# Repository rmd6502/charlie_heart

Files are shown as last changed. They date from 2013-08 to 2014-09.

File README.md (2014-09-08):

Charlie Heart
=============

https://dl.dropboxusercontent.com/u/10205003/VIDEO0005.mp4
Charlieplexed Heart for Mother's day, etc.  The files are for EAGLE cad, will gladly accept pull requests with Kicad files.

David Reeves made a set of step-by-step instructional photos at https://www.flickr.com/photos/dcreeves2000/sets/72157640155673266/

Annie Hsu made me an instructional video at https://www.dropbox.com/s/pq46bvkq2qu05k4/LED%20Heart-SD%20for%20Apple%20Devices.m4v

Parts Manifest
==============

1.  Heart-shaped circuit board
1.  5 x 3Ω resistors, marking "3R0"
1.  1 x 1kΩ resistor, marking "102"
1.  1 x .1µf capacitor, tan
1.  1 x mosfet transistor
1.  1 x pushbutton switch
1.  1 x preprogrammed ATTiny85 processor
1.  20 x red LEDs
1.  1 x battery clip
1.  1 x CR2032 battery

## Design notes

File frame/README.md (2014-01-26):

Updated the case with an all new Openscad one!

Print 2, and you can run a ribbon through the slots for instant gifting.

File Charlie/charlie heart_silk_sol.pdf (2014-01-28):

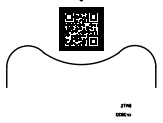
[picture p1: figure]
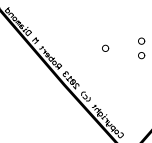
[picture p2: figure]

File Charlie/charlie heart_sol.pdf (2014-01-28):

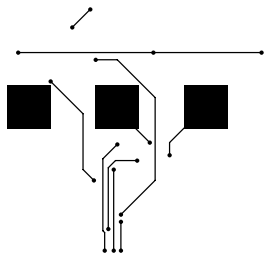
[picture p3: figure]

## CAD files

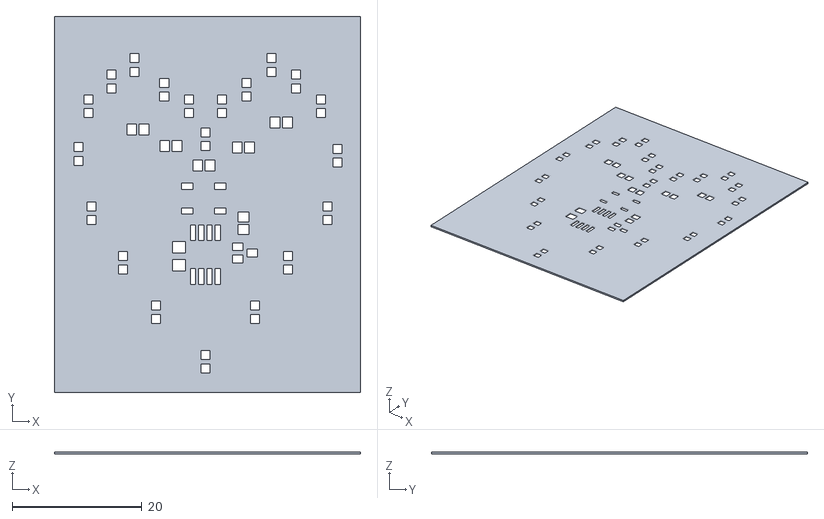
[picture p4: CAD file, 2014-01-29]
Charlie/template.stl
47.1 x 58.0 x 0.3

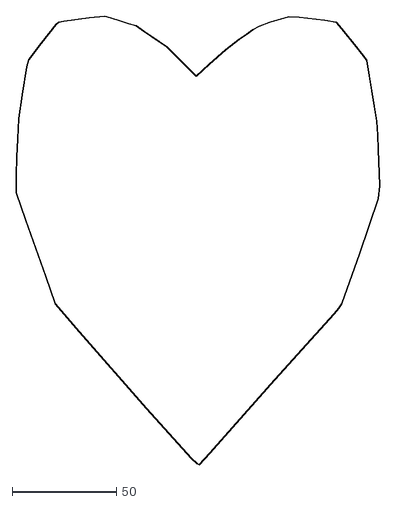
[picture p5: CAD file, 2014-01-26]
frame/inner_heart.dxf
174.2 x 214.6

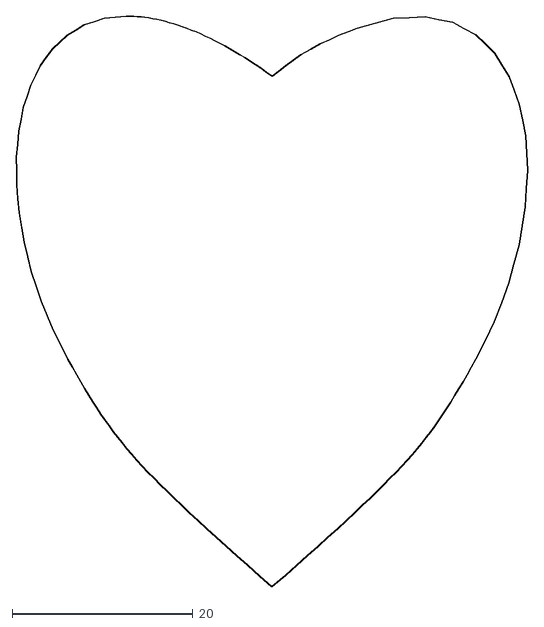
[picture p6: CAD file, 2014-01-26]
frame/outer_heart.dxf
56.6 x 63.2

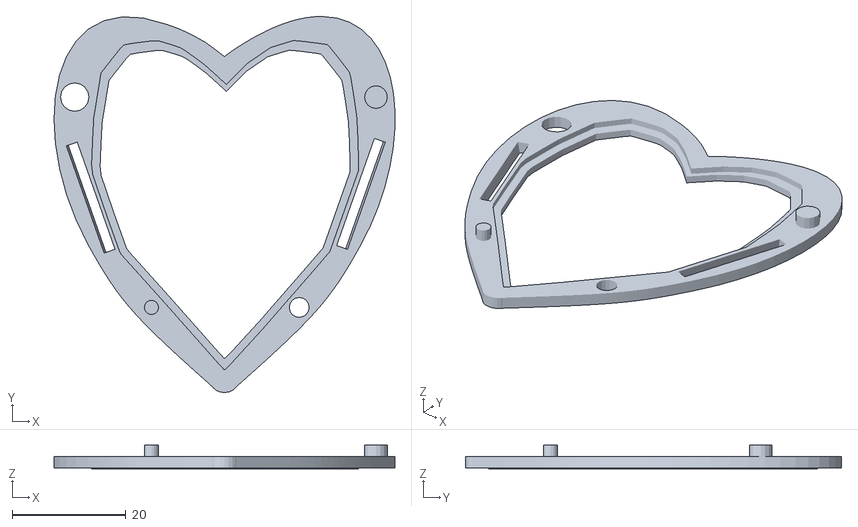
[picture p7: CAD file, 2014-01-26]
frame/heart_board.stl
60.0 x 66.2 x 4.20

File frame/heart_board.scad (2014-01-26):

rotate([0,180,0]) union() {
	difference() {
		translate([-30,0,0]) linear_extrude(2) resize([60,0,0],auto=true) import("outer_heart.dxf");
		translate([-23.5,5,0]) linear_extrude(2) resize([47,0,0],auto=true) import("inner_heart.dxf");
		translate([26.5,53,1]) cylinder(r=2.5,h=2,center=true,$fn=16);
		translate([-13,16,1]) cylinder(r=1.75,h=2,center=true,$fn=16);
		translate([-21.5,26.2,0]) rotate([0,10,19.4]) cube([2,20,3]);
		translate([19.5,26.2,-.5]) rotate([0,-10,-19.4]) cube([2,20,3]);
		// For pointed tip comment this line and the last
		translate([-2.4,0,0]) cube([5,2,2]);
	}
	translate([0,0,1]) difference() {
		translate([-23.5,5,0]) linear_extrude(1.2) resize([47,0,0],auto=true) import("inner_heart.dxf");
		translate([-22,7,0]) linear_extrude(1.2) resize([44,0,0],auto=true) import("inner_heart.dxf");
	}
	translate([-26.5,53,-1]) cylinder(r=2,h=2,center=true,$fn=16);
	translate([13,16,-1]) cylinder(r=1.25,h=2,center=true,$fn=16);
	// for pointed tip comment this line and the indicated one above
translate([0.16,3,0]) scale([1.1,.9,1]) linear_extrude(2) circle(2.2,$fn=20);
}

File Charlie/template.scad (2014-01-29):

render(2) difference() {
	cube([47.15,57.95,.3]);
	minkowski() { 
		translate([3,3,0]) linear_extrude(.2) import ("charlie heart_top_paste.dxf");
		cube(.2);
	}
}

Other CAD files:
Charlie/charlie heart_top_paste.dxf

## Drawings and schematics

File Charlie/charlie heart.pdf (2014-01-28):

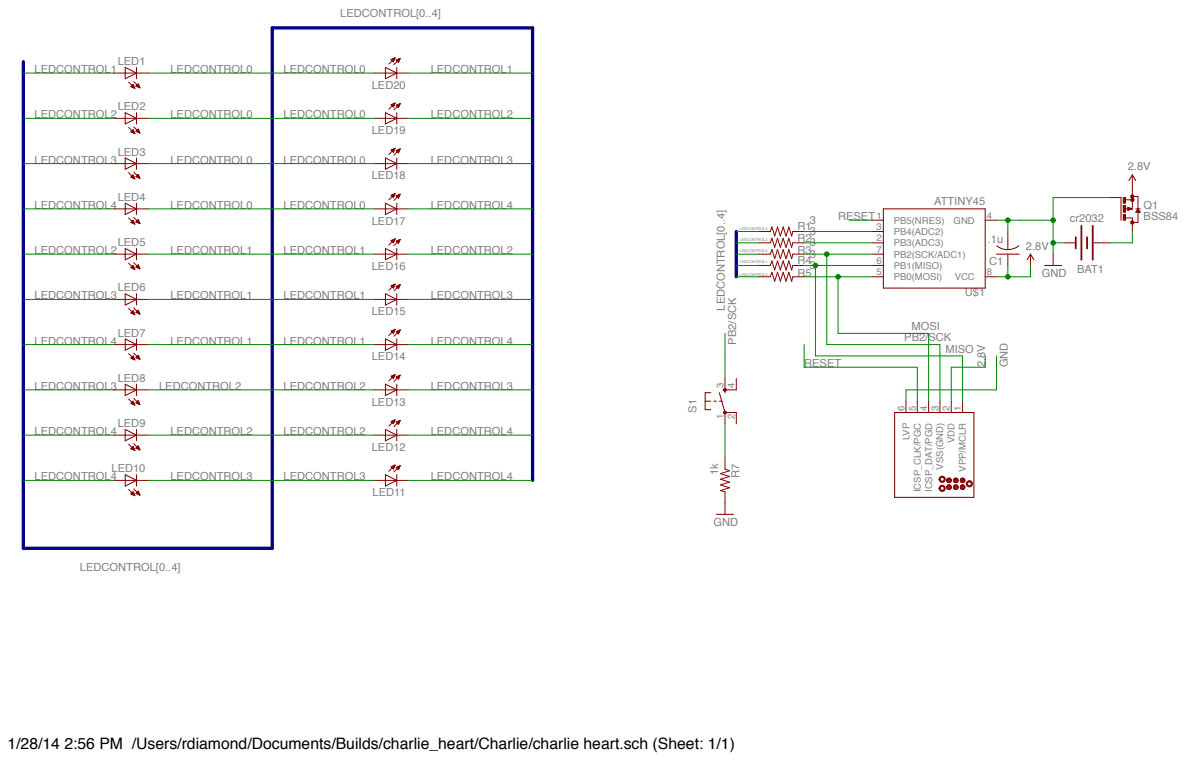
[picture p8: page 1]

LED2 LEDCONTROL2 LEDCONTROL0 | LED20 LEDCONTROL0 LEDCONTROL2

LED3 LEDCONTROL3 LEDCONTROL0 | LED19 LEDCONTROL0 LEDCONTROL3

LED4 LEDCONTROL4 LEDCONTROL0 | LED18 LEDCONTROL0 LEDCONTROL4

LED6 LEDCONTROL3 LEDCONTROL1 | LED16 LEDCONTROL1 LEDCONTROL3

LED7 LEDCONTROL4 LEDCONTROL1 | LED15 LEDCONTROL1 LEDCONTROL4

LED8 LEDCONTROL3 LEDCONTROL2 | LED14 LEDCONTROL2 LEDCONTROL3

LED9 LEDCONTROL4 LEDCONTROL2 | LED13 LEDCONTROL2 LEDCONTROL4

VPP/MCLR 1 VDD 2 VSS(GND) 3 ICSP_DAT/PGD 4 ICSP_CLK/PGC 5 LVP 6

LED10 LEDCONTROL4 LEDCONTROL3 | LED12 LEDCONTROL3 LEDCONTROL4

1/28/14 2:56 PM /Users/rdiamond/Documents/Builds/charlie_heart/Charlie/charlie heart.sch (Sheet: 1/1)

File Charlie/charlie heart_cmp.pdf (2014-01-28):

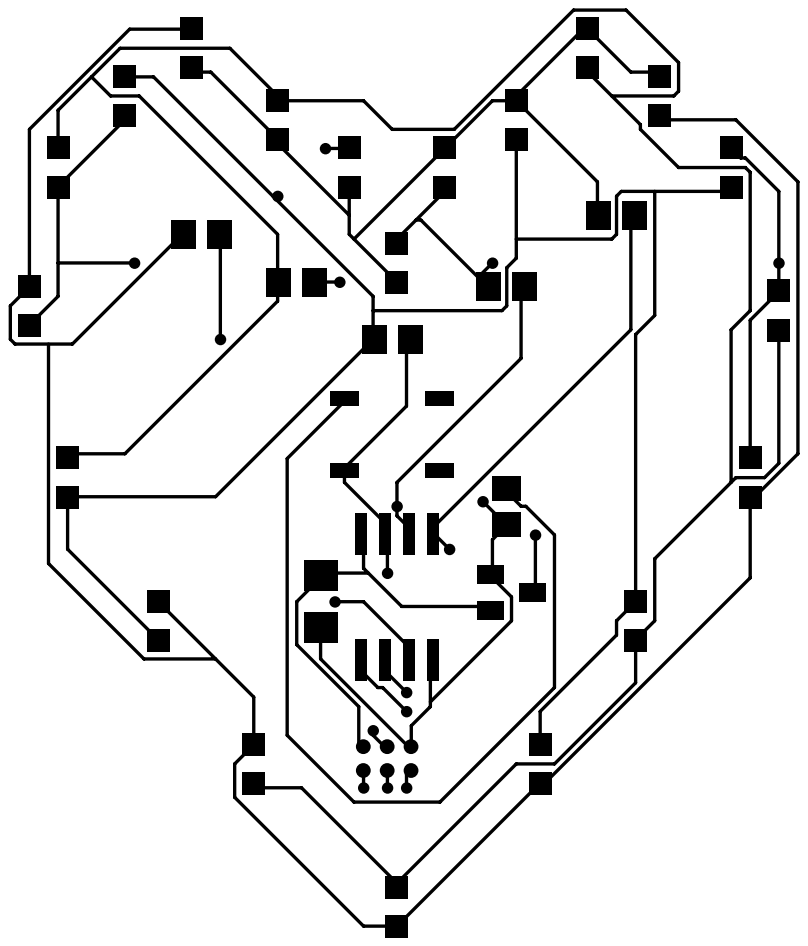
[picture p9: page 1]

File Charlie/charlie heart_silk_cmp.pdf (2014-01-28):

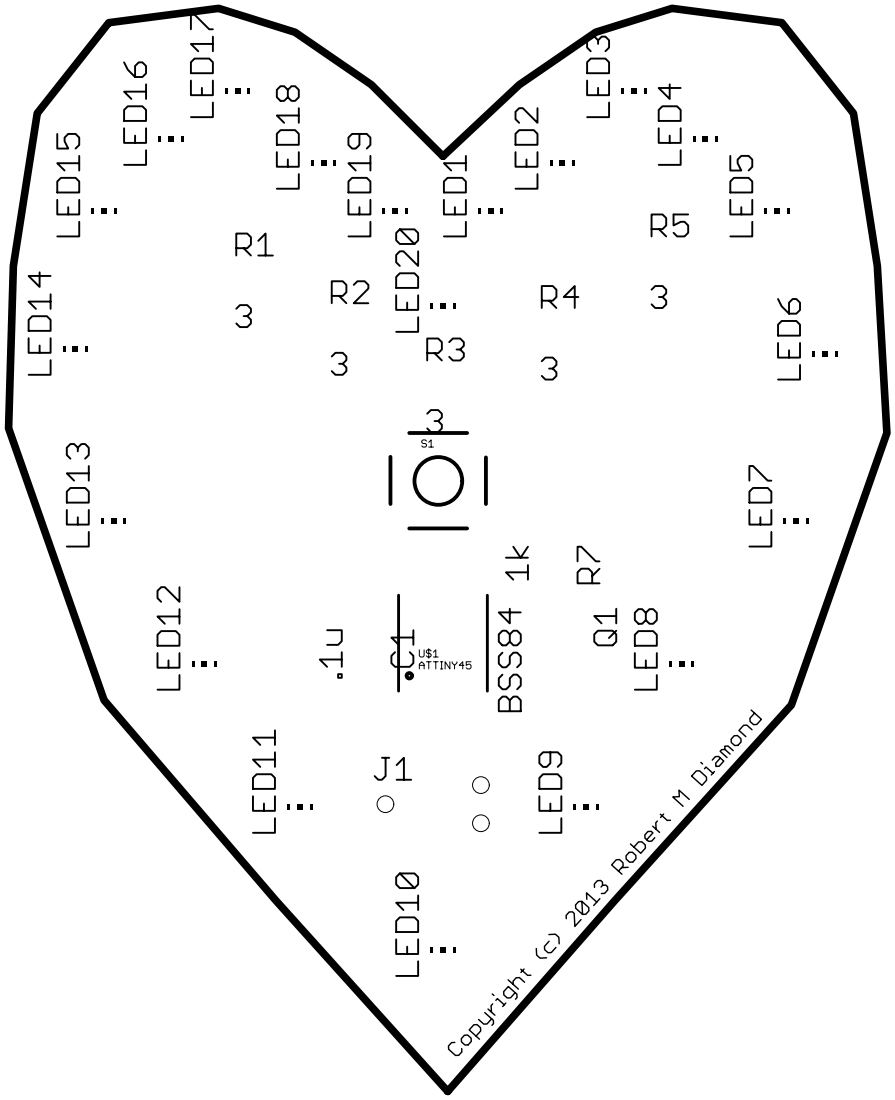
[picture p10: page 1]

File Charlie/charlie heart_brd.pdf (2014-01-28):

R5

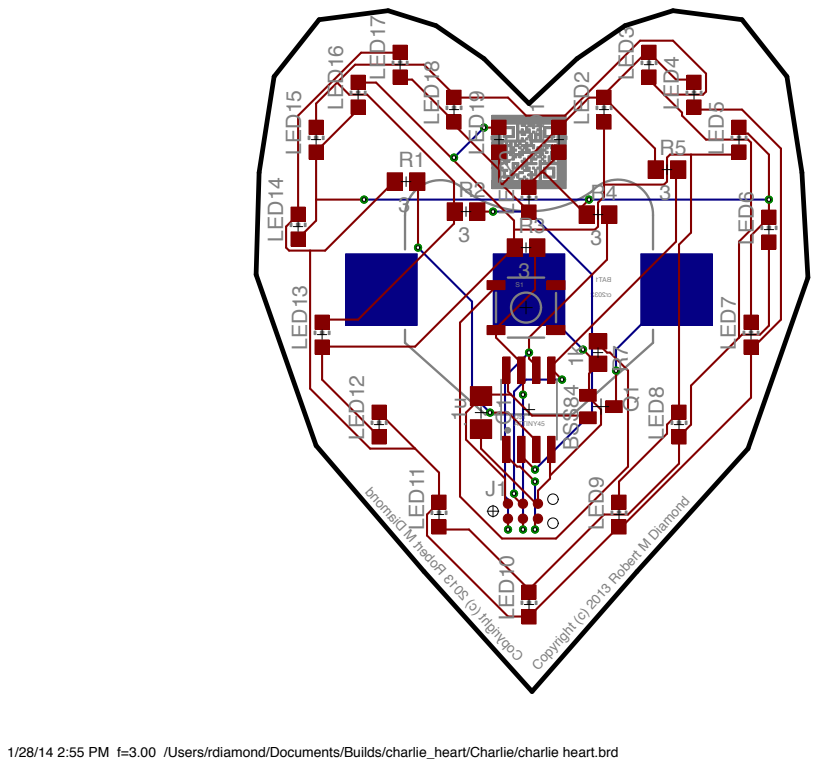
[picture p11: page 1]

1/28/14 2:55 PM f=3.00 /Users/rdiamond/Documents/Builds/charlie_heart/Charlie/charlie heart.brd

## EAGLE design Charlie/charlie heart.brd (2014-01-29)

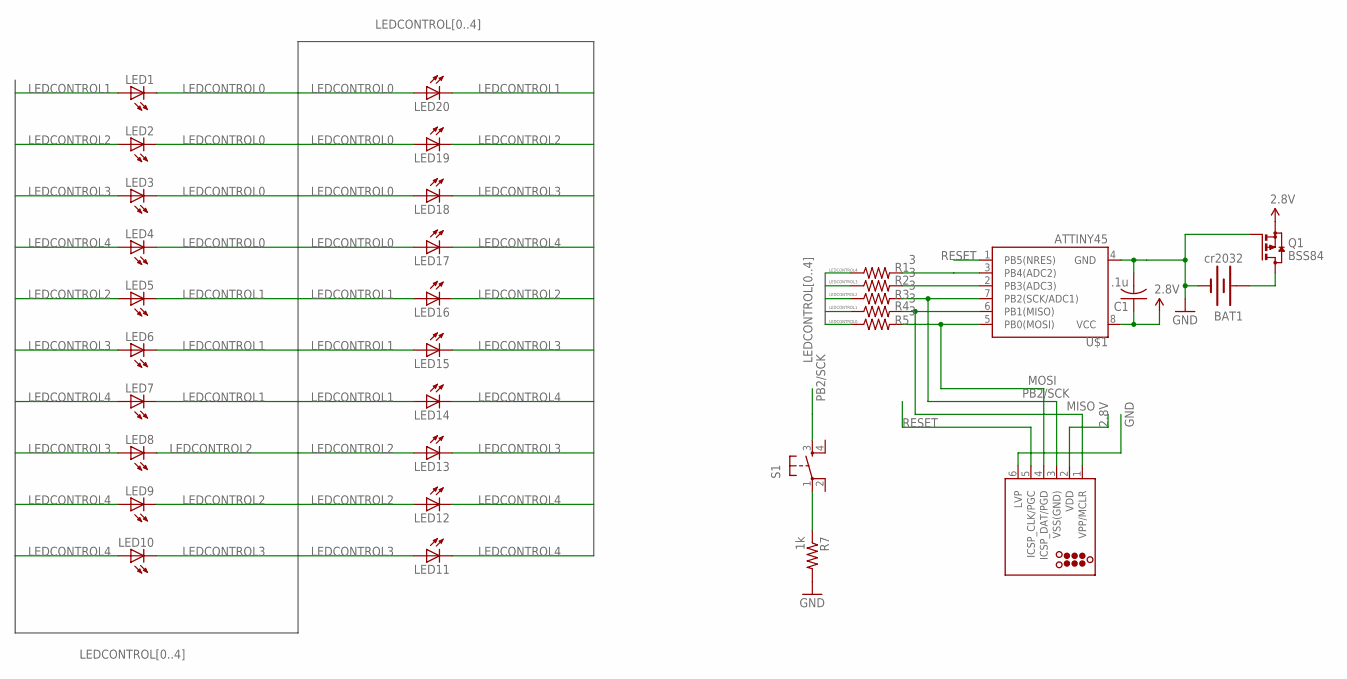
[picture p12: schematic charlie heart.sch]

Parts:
BAT1: cr2032; BATTCON_20MM
C1: .1u; C1206
J1: TC2030-MCP-NL
LED1, LED2, LED3, LED4, LED5, LED6, LED7, LED8, LED9, LED10, LED11, LED12, LED13, LED14, LED15, LED16, LED17, LED18, LED19, LED20: LEDCHIP-LED0805; CHIP-LED0805
Q1: BSS84; SOT23
R1, R2, R3, R4, R5: 3; R0805
R7: 1k; R0805
S1: TAC_SWITCHSMD; TACTILE_SWITCH_SMD
U$1: ATTINY45; SO08-EIAJ

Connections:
2.8V: C1.1, J1.2 (VDD), Q1.2 (S), U$1.8 (VCC)
GND: BAT1.2 (-), C1.2, J1.6 (LVP), Q1.1 (G), R7.2, U$1.4 (GND)
LEDCONTROL0: LED1.C, LED2.C, LED3.C, LED4.C, LED17.A, LED18.A, LED19.A, LED20.A, R5.1
LEDCONTROL1: LED1.A, LED5.C, LED6.C, LED7.C, LED14.A, LED15.A, LED16.A, LED20.C, R4.1
LEDCONTROL2: LED2.A, LED5.A, LED8.C, LED9.C, LED12.A, LED13.A, LED16.C, LED19.C, R3.1
LEDCONTROL3: LED3.A, LED6.A, LED8.A, LED10.C, LED11.A, LED13.C, LED15.C, LED18.C, R2.1
LEDCONTROL4: LED4.A, LED7.A, LED9.A, LED10.A, LED11.C, LED12.C, LED14.C, LED17.C, R1.1
MISO: J1.1 (VPP/MCLR), R4.2, U$1.6 (PB1(MISO))
MOSI: J1.4 (ICSP_DAT/PGD), R5.2, U$1.5 (PB0(MOSI))
unnamed: BAT1.1 (+), Q1.3 (D)
unnamed: R7.1, S1.1
unnamed: R2.2, U$1.2 (PB3(ADC3))
unnamed: R1.2, U$1.3 (PB4(ADC2))
PB2/SCK: J1.3 (VSS(GND)), R3.2, S1.3, U$1.7 (PB2(SCK/ADC1))
RESET: J1.5 (ICSP_CLK/PGC), U$1.1 (PB5(NRES))

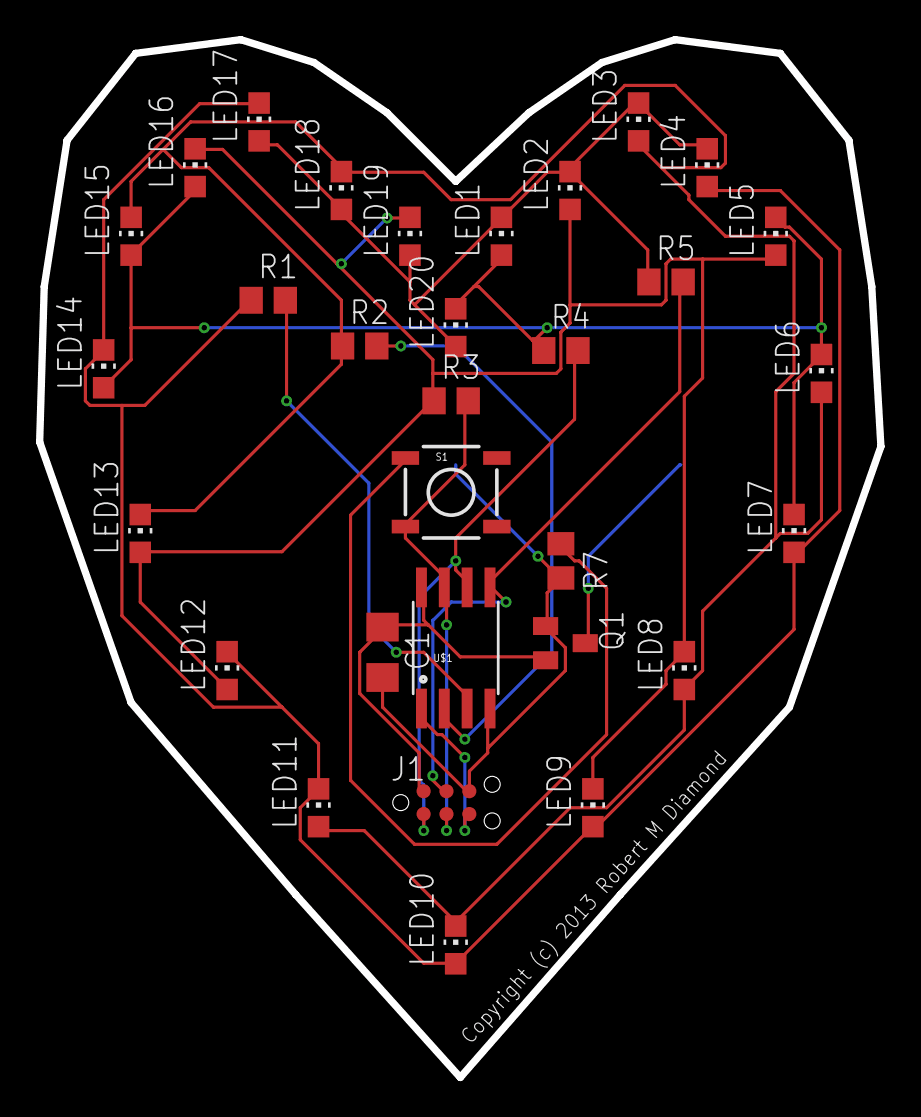
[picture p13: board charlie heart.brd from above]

Board: 2 copper layers, 46.7 x 57.7 mm, 32 parts (1 on the bottom side), 15 nets.

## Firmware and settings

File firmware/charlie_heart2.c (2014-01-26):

#include <avr/interrupt.h>
#include <avr/io.h>
#include <avr/sleep.h>
#include <string.h>
#include <util/delay.h>

#include "charlie.h"

#define NUM_PINS 20
#define PULSE_COUNTS_PER_STATE 8
#define SCANNER_COUNTS_PER_STATE 8
#define ALT_COUNTS_PER_STATE 25
#define BUTTON_PIN 2

int16_t countsPerState[] = {
	0, SCANNER_COUNTS_PER_STATE, PULSE_COUNTS_PER_STATE, ALT_COUNTS_PER_STATE
};

typedef enum _States {
	POWEROFF = 0, SCANNER, PULSE, ALTERNATE, NUM_STATES
} States;

volatile uint8_t buffer[NUM_PINS] = {
	0
};

void initialize(void);
uint16_t pulseCounts();

int8_t mod(int8_t q, int8_t d)
{
	int8_t r = q % d;
	if (r < 0) {
		r += d;
	}
	return r;
}

int main()
{
	uint16_t last_cycle_count = 0;
	int8_t state = 0;
	int8_t dir = 1;
	int16_t count = 0;
	int16_t counts_per_state = pulseCounts();
	uint8_t last_button=0;
	States runState = PULSE;
	initialize();
	while(1) {
		switch(runState) {
		case SCANNER:
			// state goes from 0 to 19
			if (state > 2) {
				buffer[mod(state - 4,20)] = 0;
			}
			if (state > 1) {
				buffer[mod(state - 3,20)] = 1;
			}
			if (state > 0) {
				buffer[mod(state - 2,20)] = 4;
			}
			buffer[mod(state - 1,20)] = 15;
			if (state < 20) {
				buffer[mod(state,20)] = 4;
			}
			if (state < 19) {
				buffer[state+1] = 1;
			}
			if (state < 18) {
				buffer[state+2] = 0;
			}

			state += dir;
			if (state == 0 || state == 20) {
				dir = -dir;
			}
			break;
		case PULSE:
			// state goes from 0 to 29
			// 0-4 up, 5-9 down, 10-14 up, 15-19 down, 20-29 idle
			if (state < 5 || (state > 9 && state < 15)) {
				memset((void *)buffer, (1 + (state % 5)) * 3, sizeof(buffer));
			} else if (state < 10 || (state > 14 && state < 20)) {
				memset((void *)buffer, (5 - (state % 5)) * 3, sizeof(buffer));
			} else {
				memset((void *)buffer, 0, sizeof(buffer));
			}
			++state;
			if (state == 30) {
				state = 0;
			}
			break;
		case ALTERNATE: {
			for (int ledNum = 0; ledNum < NUM_PINS-1; ledNum += 2) {
				buffer[ledNum] = state;
				buffer[ledNum+1] = 15 - state;
			}
			state = 15 - state;
		}
		break;
		case POWEROFF:
		default:
			memset((void *)buffer, 0, sizeof(buffer));
			break;
		}

		count = 0;
	    if (runState == PULSE) {
			counts_per_state = pulseCounts();
		}
		while (count < counts_per_state || counts_per_state == 0) {
			uint16_t shadow_cycle_count = cycle_count;
			last_cycle_count = shadow_cycle_count;

			cli();
			while (last_cycle_count == shadow_cycle_count) {
				sleep_enable();
				sei();
				sleep_cpu();
				sleep_disable();

				cli();
				shadow_cycle_count = cycle_count;

				if (button_state != last_button) {
					last_button = button_state;
					if (!last_button) {
						state = 0;
						dir = 1;
						runState++;
						if (runState == NUM_STATES) {
							runState = POWEROFF;
						}
						if (runState == PULSE) {
							counts_per_state = pulseCounts();
						} else {
							counts_per_state = countsPerState[runState];	
						}
						
						if (runState == POWEROFF) {
							prepare_for_sleep();
							memset((void *)buffer, 0, sizeof(buffer));
							set_sleep_mode(SLEEP_MODE_PWR_DOWN);
							last_button = button_state;
						} else {
							return_from_sleep();
							set_sleep_mode(SLEEP_MODE_IDLE);
						}
					}
					_delay_ms(1);
				}
			}
			sei();
			++count;
		}
	}
}

void initialize(void)
{
	// initialize charlieplexing
	static LedPins ledPins[NUM_PINS];
	uint8_t count = 0;
	for (uint8_t i=0; i < 4; ++i) {
		for (uint8_t j = i+1; j < 5; ++j) {
			ledPins[count].highpin = j;
			ledPins[count].lowpin = i;
			ledPins[19 - count].highpin = i;
			ledPins[19 - count].lowpin = j;
			++count;
		}
	}
	charlie_init(1,NUM_PINS,ledPins,buffer,BUTTON_PIN);
	set_sleep_mode(SLEEP_MODE_IDLE);
    ADCSRA = 0;
	ADMUX = _BV(REFS1) | 0xf;
	ADCSRA = _BV(ADEN) | _BV(ADSC) | (7 << ADPS0);
}

uint16_t map(int16_t reading, int16_t in_min, int16_t in_max, int16_t out_min, int16_t out_max)
{
	return (reading - in_min) * (out_max - out_min) / (in_max - in_min) + out_min;
}

uint16_t constrain(int16_t reading, int16_t in_min, int16_t in_max)
{
    if (reading < in_min) {
        reading = in_min;
    }
    if (reading > in_max) {
        reading = in_max;
    }
    return reading;
}

uint16_t pulseCounts()
{
	static uint16_t temperature = 0;
	static uint16_t pulseCounts = PULSE_COUNTS_PER_STATE;
    static int min_temp = 290;
    static int max_temp = 300;
	
	if (!(ADCSRA & _BV(ADSC))) {
		temperature = constrain(ADCL + (ADCH << 8),min_temp,max_temp);
	    ADMUX = _BV(REFS1) | 0xf;
		ADCSRA |= _BV(ADSC);
		pulseCounts = map(temperature, min_temp, max_temp,20,3);
	}
	return pulseCounts;
}

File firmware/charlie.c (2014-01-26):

// Copyright (c) 2012 Robert M. Diamond All Rights Reserved.
//
#include <avr/interrupt.h>
#include <avr/io.h>
#include <inttypes.h>
#include <stdlib.h>
#include <string.h>

#include "charlie.h"

// buffer bytes, only lower 4 bits are significant
static volatile uint8_t *buffer;

static volatile uint8_t timer = 0;
static volatile uint8_t num_rows, num_columns;
static volatile uint8_t *bufPtr = 0;
static volatile LedPins *ledPtr = 0;
volatile uint16_t cycle_count;
volatile uint8_t button_state = 0;
static volatile uint8_t button_pin = 0;
static volatile uint8_t sleep_state = 0;
volatile uint16_t val = 0;

static volatile LedPins *ledPins;

void charlie_init(uint8_t _num_rows, uint8_t _num_columns, LedPins *led_pins, volatile uint8_t *_buffer,uint8_t _button_pin)
{
	// setup the buffer
	num_rows = _num_rows;
	num_columns = _num_columns;
	ledPins = led_pins;
	buffer = _buffer;
	button_pin = _button_pin;

	bufPtr = (uint8_t *)buffer + num_rows * num_columns;
	ledPtr = ledPins + num_rows * num_columns;
	timer = 15;
	cycle_count = 0;

	PRR = ~(_BV(PRTIM0) | _BV(PRADC));
	MCUCR &= ~(1 << PUD);

	cli();
	// initialize the timer and interrupt
	TCNT0 = 0;
	OCR0A = 40;
	// interrupt at count 40, so 50kHz interrupt
	TIMSK |= _BV(OCIE0A);
	TIFR = _BV(OCF0A);
	// Start the timer at PCK/8, so 2 MHz timer clock
	// with 16 shades, that means 3125 frames/sec
	// and the interrupt routine has 320 cycles to run, including interrupt and gcc overhead
	TCCR0A = (2 << WGM00);
	TCCR0B = (2 << CS00);

	// Set up the button
	GIMSK = _BV(PCIE);
	PCMSK = _BV(PCINT2);
	GIFR = _BV(PCIF);

	sei();
}

void prepare_for_sleep()
{
	sleep_state = 1;
	timer = 16;
	TCCR0B = 0;
	DDRB = 0;
	//PORTB = 0;
	PORTB = 1 << button_pin;
}

void return_from_sleep()
{
	sleep_state = 0;
	TCCR0B = (2 << CS00);
}

ISR(TIMER0_COMPA_vect) {

	--bufPtr;
	--ledPtr;

	if (timer == 16) {
		button_state = (PINB >> button_pin) & 1;
		--timer;
		return;
	}
	if (*bufPtr >= timer) {
		DDRB = _BV(ledPtr->highpin) | _BV(ledPtr->lowpin);
		PORTB = _BV(ledPtr->highpin);
	} else {
		DDRB = 0;
		PORTB = 0;
	}

	if (bufPtr == buffer) {
		bufPtr = (uint8_t *)buffer + num_rows * num_columns;
		ledPtr = ledPins + num_rows * num_columns;
		--timer;
		if (timer == 0) {
			timer = 16;
			++cycle_count;
			DDRB = 0;
			PORTB = 1 << button_pin;
		}
	}
}

ISR(PCINT0_vect)
{
	if (!sleep_state) {
		return;
	}
	button_state = (PINB >> button_pin) & 1;
}

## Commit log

2012-08-20 initial import
    [charlie.brd, charlie.sch]
2012-08-20 make it compile, but I'm sure it doesn't work yet
    [charlie.c]
2013-05-12 use timer0 and PRR to conserve battery
2013-05-12 add 3d printed frame files
    [heart.skp, heartuntitled.stl, heartwring.skp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]
2013-08-03 add proper board file, and add mosfet for reverse battery safety
    [charlie heart.brd, charlie heart.sch, charlie.brd]
2013-08-03 add mode switch
    [charlie heart.brd, charlie heart.sch]
2013-08-03 add copyright and email address QR
    [charlie heart.brd]
2013-08-03 flip qr code so it's right
    [charlie heart.brd]
2013-08-04 remove pullup resistor
    [charlie heart.brd, charlie heart.sch]
2013-08-10 button, pll clock
2013-08-27 update board font, button pin
    [charlie heart.brd]
2013-08-29 also add button support
2013-08-29 multiple states, power down
2013-09-08 button support
2013-09-22 further enhancements. enable adc when using it
2013-10-10 adc tests
2014-01-26 more adc
2014-01-26 update frame
    [heart.skp, heart_board.scad, heart_board.stl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]
2014-01-26 constrain reading to avoid hangs
    [charlie_heart2.c]
2014-01-28 add solder paste template
    [charlie heart_top_paste.dxf, template.scad, template.stl]
2014-01-29 update template
    [charlie heart.brd, charlie heart_top_paste.dxf, template.scad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]

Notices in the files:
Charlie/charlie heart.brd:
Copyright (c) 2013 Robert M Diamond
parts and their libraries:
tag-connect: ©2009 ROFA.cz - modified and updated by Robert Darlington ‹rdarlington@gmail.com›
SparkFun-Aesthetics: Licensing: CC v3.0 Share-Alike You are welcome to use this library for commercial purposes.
